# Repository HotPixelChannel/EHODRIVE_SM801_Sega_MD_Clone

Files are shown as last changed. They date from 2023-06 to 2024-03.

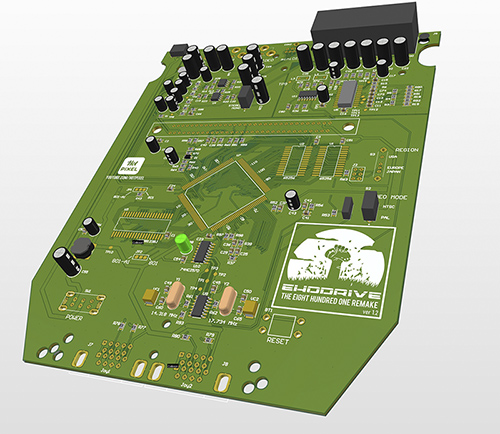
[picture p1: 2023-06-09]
img.jpg

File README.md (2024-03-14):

# EHODRIVE
## _Клон Sega Megadrive на чипе SM801_

N|Solid

### https://www.youtube.com/watch?v=zfkC4TfzuUU

## Особенности проекта:
- Переключение на лету PAL/NTSC (для каждого режима отдельный кварц)
- Переключение регионов USA/Europe/Japan
- Питание консоли осуществляется через USB type-C
- За вывод картинки отвечает внешний кодер CXA1645/CXA2075
- Вывод картинки: SCART (RGB), (RCA, miniDIN9)
- Переключение режимов стерео/моно звука

## Примечания
- Мультиплексор 74HC257D в корпусе 652
- ОУ 4558d можно заменить на любой аналог BA715, LA6458, MB3607M, AN1358, AN6562, AN6552, AN6572, AN4558, AN6552, LA6552 и т.д. 
- ОЗУ 65256 - em51m256a, hy62256alj, 65256blfp или аналогичная 32K*8 SRAM

Для легкой и быстрой сборки консоли потребуется другая рабочая консоль на чипе SM801 или его клонах. На плате учтен вариант, когда порты джойстиков сломаны или утерены, поэтому есть возмоность установки обычных разъемов DB-9M. VC1 и VC2 можно не устанавливать, они требуется для небольшой подстройки частоты при использовании проблемных кварцев. Сильно желателен вариант установки кодера CXA2075, с ним качество картинки наилучшее. В случае установки CXA1645, придется подбирать индуктивность L3 и L4, обычно приемлимое значение находится в промежутке 10-75 мкГн. В случае слишком темной или слишком яркой картинки (в зависимости от установленного мультипроцессора), регулировку можно произвести резисторами R3-R5, добившись Vp-p цветовых каналов на уровне 0.85-1В. R50 лучше не ставить - это подтяжка vsync, не на всех чипах работает как надо. После сборки ТЩАТЕЛЬНО отмыть от флюса, 801ый очень чувствителен к малейшей токопроводимости и может не завестись из-за плохого флюса. Если плата собрана верно, никакой настройки для успешного запуска не требуется.

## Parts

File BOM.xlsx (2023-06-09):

Comment | Description | Designator | Quantity
RESET |  | BT1 | 1
0.1 uF | 0805 | C1, C2, C3, C11, C12, C13, C16, C21, C23, C24, C42, C45, C51, C54, C57, C59, C80 | 17
10 uF |  | C4, C5, C6, C7, C8, C9, C26, C38, C53, C56 | 10
100 uF |  | C14, C52 | 2
47 pF | 0805 | C15 | 1
47 uF |  | C17, C43, C62 | 3
100 pF | 0805 | C18, C37, C39, C40, C41, C63, C74 | 7
470 pF | 0805 | C19, C20 | 2
330 uF |  | C22 | 1
10 nF | 0805 | C25 | 1
220 uF |  | C28, C31, C32, C33, C34, C35, C67, C68, C69, C70, C71, C72 | 12
24 pF | 0805 | C29 | 1
10 pF | 0805 | C36, C73 | 2
30 pF | 0805 | C49, C50, C75 | 3
1000 uF |  | C55 | 1
47 uF |  | C58 | 1
15 pF | 0805 | C60, C65 | 2
2200 pF | 0805 | C66 | 1
39 pF | 0805 | C76 | 1
100 uF |  | C81 | 1
Cartridge slot |  | Con1 | 1
miniDIN9 |  | CON2 | 1
1N4148W | DIODE GEN PURP 75V 150MA SOD123 | D1 | 1
SW MODE HEADER | Connector | J1 | 1
REGION HEADER | Header, 3-Pin, Dual row | J2 | 1
USB TYPE-C | Connector | J3 | 1
COMP_VIDEO | Connector | J4 | 1
SCART | Connector | J5 | 1
SL | Connector | J6 | 1
D Connector 9 Long | Receptacle Assembly, 9 Position, Right Angle | J7, J8 | 2
SR | Connector | J9 | 1
D Connector 9 | Receptacle Assembly, 9 Position, Right Angle | Joy1, Joy2 | 2
SM801 |  | JP1 | 1
SM801/A |  | JP2 | 1
10 uH |  | L1 | 1
10uH |  | L2 | 1
Inductor |  | L3, L4 | 2
75 | 0805 | R1, R2, R30, R31, R32, R33, R35 | 7
7.5k | 0805 | R3, R4, R5 | 3
1k | 0805 | R6, R13, R39, R97, R98 | 5
47k | 0805 | R7, R9, R10, R12, R20, R23, R29, R70 | 8
20k | 0805 | R8, R11 | 2
10k | 0805 | R15, R21, R22, R37 | 4
1.5k | 0805 | R16 | 1
1.8k | 0805 | R17, R18, R19 | 3
22k | 0805 | R24, R25, R28 | 3
15k | 0805 | R36, R96 | 2
150 | 0805 | R40 | 1
330 | 0805 | R43, R77, R78, R79, R80 | 5
1.2k | 0805 | R50, R53, R68 | 3
100 | 0805 | R51 | 1
2.2k | 0805 | R52, R56, R64, R65, R95 | 5
56 | 0805 | R57, R58, R59, R60 | 4
1M | 0805 | R61, R62 | 2
3.3k | 0805 | R63, R66, R76 | 3
180 | 0805 | R71, R72 | 2
2.6k | 0805 | R75 | 1
5.6k | 0805 | R90, R91, R92 | 3
4.7k | 0805 | R93 | 1
000 | 0805 | R99 | 1
SW_MONO | SS12D07VG4NSGAPA | S1 | 1
SW_MODE | SS12D07VG4NSGAPA | S2 | 1
REGION-SW | SK13D08G5E | S3 | 1
POWER SW |  | SW1 | 1
Test point |  | TP1, TP2, TP3, TP4, TP5, TP6, TP8, TP9, TP10, TP11, TP12, TP13, TP14, TP15 | 14
65256 |  | U1, U2 | 2
HM538123BJ |  | U3 | 1
4558 | Operation amp | U4, U6 | 2
CXA1645M (CXA2075M) | Video coder | U5 | 1
SM801 | SM801 | U7 | 1
74hc04 |  | U9 | 1
74HC257D | Integrated Circuit | U10 | 1
HEF4066BT | Integrated Circuit | U11 | 1
4-10 pF | Capacitor | VC1, VC2 | 2
14.318 MHz | Crystal or Oscillator | Y1 | 1
17.734 MHz | Crystal or Oscillator | Y2 | 1

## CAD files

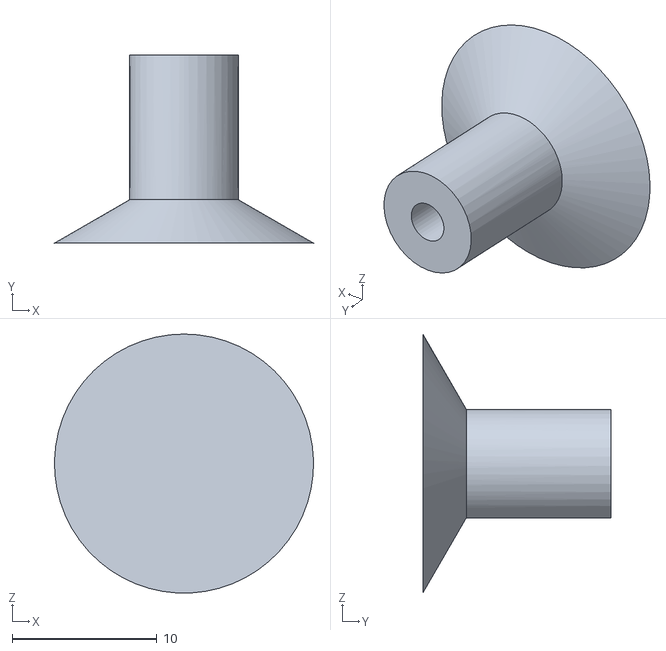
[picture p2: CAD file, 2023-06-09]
3D printing/Mounting_rack.STL
17.9 x 13.0 x 17.9

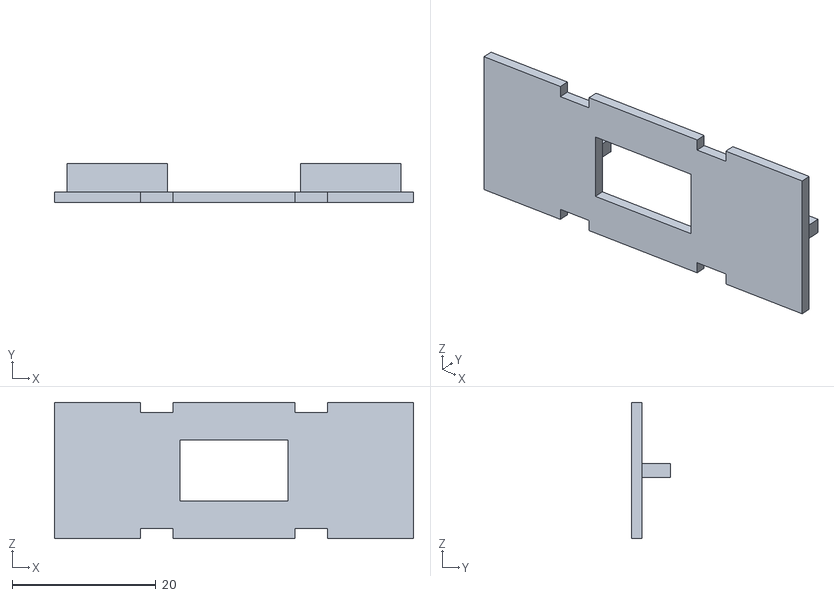
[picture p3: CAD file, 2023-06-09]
3D printing/Power_holder.STL
50.0 x 5.40 x 19.0

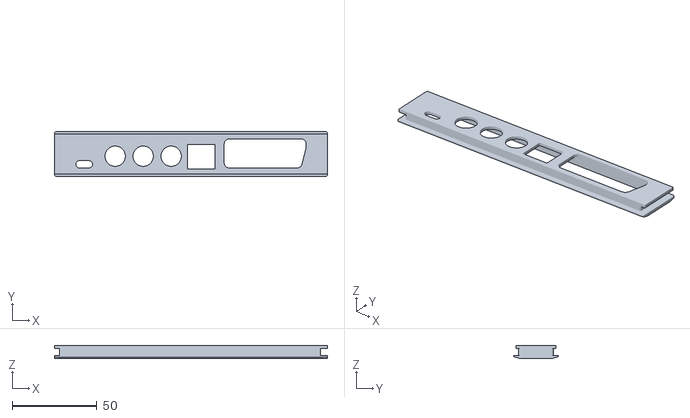
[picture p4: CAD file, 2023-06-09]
3D printing/Back_cover.STL
161.0 x 26.5 x 7.50

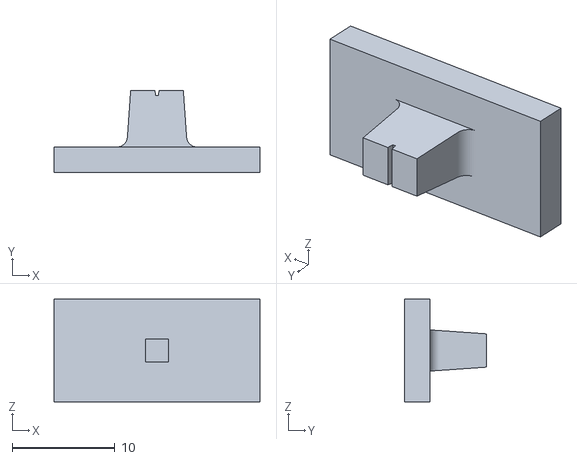
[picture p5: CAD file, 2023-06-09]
3D printing/Switcher.STL
20.0 x 8.00 x 10.0

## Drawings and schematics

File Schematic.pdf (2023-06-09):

# R70 MRES

# 9 10 MiniDIN⁹

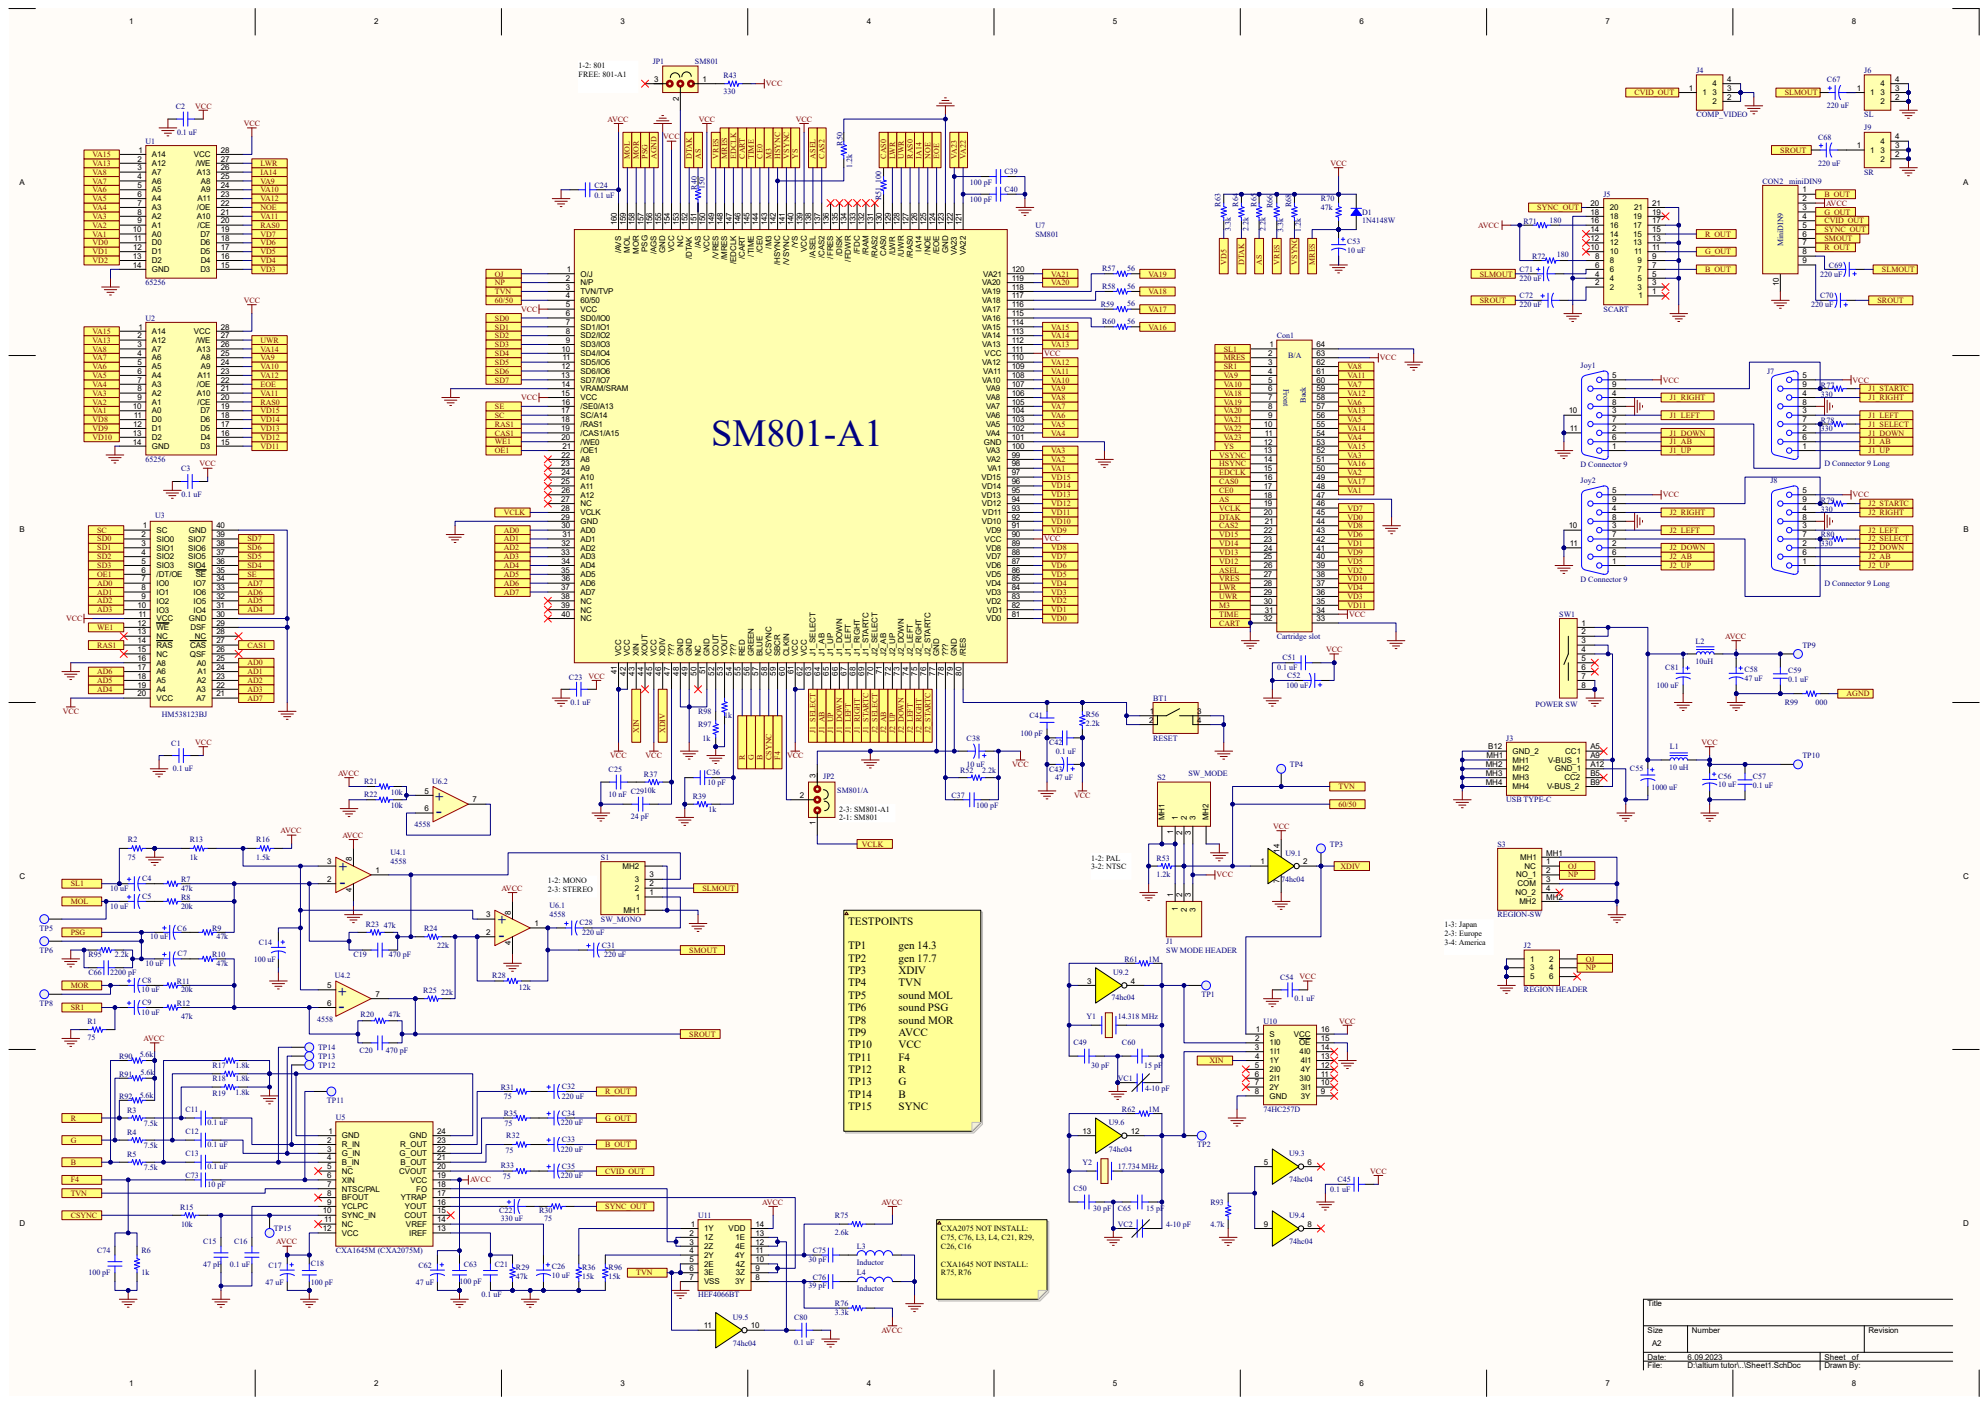
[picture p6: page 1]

SCART MOL MOR PSG

A7 21 A3 22 A2 23 A1 24 A0 25 QSF 26 CAS 27 NC 28 DSF 29 GND 30 IO4 31 IO5 32 IO6 33 IO7 34 SE 35 SIO4 36 SIO5 37 SIO6 38 SIO7 39 GND 40

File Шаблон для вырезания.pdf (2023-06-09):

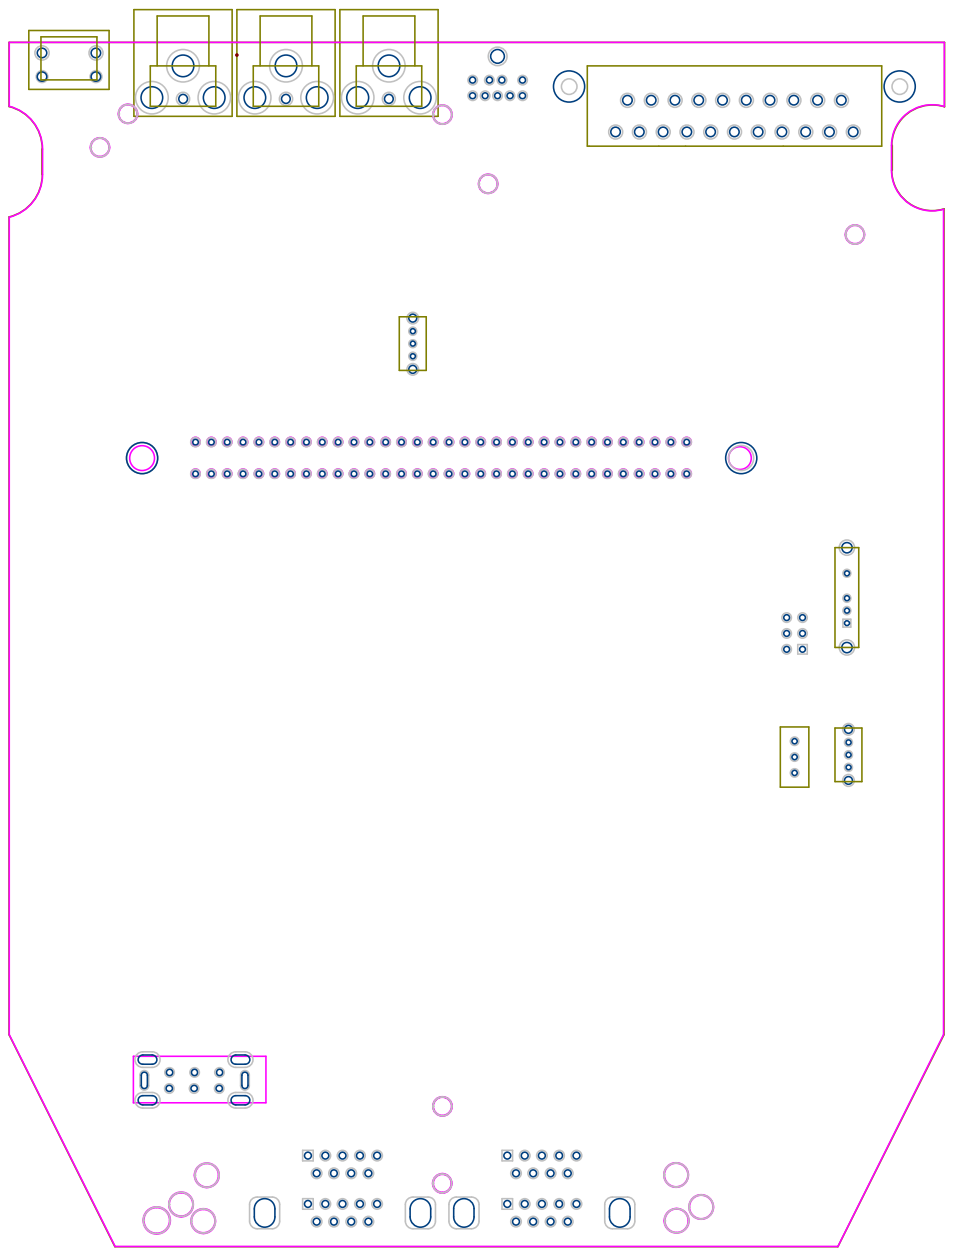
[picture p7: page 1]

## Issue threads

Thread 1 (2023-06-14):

По разводке платы

8street, 2023-06-14:
Привет!
Некоторые ошибки и дополнения:
1. Отлично, что есть вырезы в "земляном" (GND здесь и далее) полигоне, но они не совсем такие какие нужно. Возвратный путь тока огибает вырезы в полигоне, поэтому путь получается очень большой, напоминающий антенну, которая излучает и принимает помехи. В идеале земля должна быть под дорожками. На рисунке выделил овалом, там полигон не должен прерываться.
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
2. Тоже самое в звуковой части. Дорожки пересекают вырез в земляном полигоне. Из-за этого, скорее всего, и есть шум. Я бы вообще весь горизонтальный вырез убрал бы, на обоих слоях. И подкорректировал самый левый вертикальный вырез, чтобы звуковые дорожки находились над землей.
3. Немного не оптимально стоят блокировочные конденсаторы микросхем. Их GND контакт должен быть как можно ближе к GND микросхемы. Ну хотя бы повернут в ту сторону. Если же GND соединяется через переходные отверстия, то около GND вывода и GND ножки конденсатора надо переходных отверстий наделать побольше. Импеданс будет меньше.
4. В оригинальной Сеге стояли конденсаторы на каждой линии джойстика. Почему не стал делать?

HotPixelChannel, 2023-06-15:
Привет! Спасибо за обратную связь! То есть полигон видеокодера нужно соединить с цифровым полигоном? но тогда же образуется петля. Вообще, да, не подумал эту гребенку соединить переходными отверстиями с нижним слоем, он там сплошной. Виновником шума оказался мой мини монитор, у него на плате видео подмешивалось в звук. На другом компьютере с нормальным питанием шумов оказалось в разы меньше, почти не заметно. В конце видео как раз примеры сравнения трех чипов делался на нем.

8street, 2023-06-16:
> То есть полигон видеокодера нужно соединить с цифровым полигоном? но тогда же образуется петля.

Петли по GND в цифре не так сильно влияют. В некоторых случаях они снижают импеданс земли. Например, были исследования, если прикрутить материнку всеми винтами к задней проводящей стенке корпуса на проводящие стойки, то мать меньше помех производит в эфир, даже с открытым корпусом, хотя казалось бы там петель образуется дофига.

Не надо забывать про возвратный ток по земле. Ток идет не только от выхода микросхему ко входу другой микросхему, но и по земле возвращается назад, с той же частотой. В высокочастотных сигналах путь возвратного тока будет пролегать аккурат под дорожкой прямого тока (в низкочастотных ток идет напрямик). Если на пути встречается вырез, то высокочастотный возвратный ток огибает этот вырез и получается антенна, которая наводит помехи. См. рисунок.

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

Вообще, если нет уверенности, делать или не делать вырез в земле, то лучше не делать. Если не нравятся петли, можно разорвать земли вверху, в районе 9-контактного сеговского разъема.

Также не увидел необходимости отделять землю SCART разъема от земли кодера.

Плюс, какие-то дорожки еще пересекают вырезы по центру платы. Их надо перенести, чтобы они были "покрыты" землей. Ну и звуковые дорожки тоже не должны пересекать вырез.

Если уж совсем надо провести дорожки по разорванной земле, то ставятся конденсаторы для протекания через них возвратного тока.

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

> По поводу блокировочников... я почему-то всегда думал что их надо ставить ближе к питанию

По плюсу питания блокировочники правильно стоят. А вот их минус (точнее GND), у некоторых, максимально развернут от GND микросхемы. Их надо просто повернуть. И побольше переходных отверстий поблизости конденсатора и микросхемы, если его GND и GND микросхемы соединяется через разные слои. Эти переходные отверстия тоже должны располагаться не абы как, а близко к линии, соединяющей эти GND. Так как ток течет от GND микросхемы к GND конденсатора.

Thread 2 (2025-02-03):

Порядок в семе и BOM листе

KuzmenkoNikita, 2025-02-03:
Приветсвую! Вдохновился твоим проектом и сейчас Собираю его, спасибо за труды! Я столкнулся с некоторыми трудностиями при сборке:

1. В BOM листе отсутсвуют напряжения для электролитических конденсаторов. У человека, который просто умеет немного паять и решил собрать по компонентам плату могут возникнуть трудности при покупке компонентов. (Я сам забыл про эту деталь, распечатал лист, отправился в местный магазин радиодеталей и нарвался на закономерный вопрос продавца: "А какое напряжение?". )

2. Несоответствие номиналов конденсаторов на электрической схеме и в BOM листе (по факту неправильно заполненное описание компонента)

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

Понятно, что на самой схеме текстом написан номинал, но вот можно ли верить значению напряжения, указанному в поле description (Возможно я заблуждаюсь, но 80 В тут с избытком)?

Было бы неплохо навести порядок в схеме электрической и сформировать более дружелюбный BOM лист. Если что могу помочь с этим

baralgin1003, 2025-02-03:
Приветствую! дескрипшены в альтиуме будут все одинаковые, так как все однотипные компоненты размножались по схеме простым клонированием. Емкость в поле Comment будет верная (она и отображается на схеме).
а по поводу напряжений - в схеме не предусмотрено напряжение выше 5в, соответственно конденсаторы можно ставить на 10-16в. напряжение на конденсаторах - это напряжение пробоя. При сборке нужно сверяться со схемой, проект альтиума выложил только для тех, у кого чешутся руки изменить плату.

HotPixelChannel, 2025-02-03:
Приветствую! дескрипшены в альтиуме будут все одинаковые, так как все однотипные компоненты размножались по схеме простым клонированием. Емкость в поле Comment будет верная (она и отображается на схеме).
а по поводу напряжений - в схеме не предусмотрено напряжение выше 5в, соответственно конденсаторы можно ставить на 10-16в. напряжение на конденсаторах - это напряжение пробоя. При сборке нужно сверяться со схемой, проект альтиума выложил только для тех, у кого чешутся руки изменить плату.
